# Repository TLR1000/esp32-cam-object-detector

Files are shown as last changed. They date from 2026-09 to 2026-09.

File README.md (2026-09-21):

# ESP32-CAM Object Detector / WildCam

Project voor een AI-Thinker ESP32-CAM met OV2640-camera. Eerste stap: camerabeeld live bekijken via het eigen wifi-netwerk van de ESP32-CAM. Bewegingsdetectie en de backend zijn beschreven in de ontwerpdocumenten en nog niet geïmplementeerd.

## Cameratest

De eerste sketch staat in [`camera-test`](camera-test/README.md), inclusief PlatformIO-configuratie, Arduino-sketch en aansluit-/flashinstructies.

Na flashen: voeding uit, GPIO0-GND-jumper verwijderen en opnieuw inschakelen. Met lokale wifi-instellingen in `camera-test/CameraTest/secrets.h` verbindt de camera met dat netwerk; open **http://wildcam-test.local/** of het IP-adres uit de seriële uitvoer. Deze instellingen blijven buiten Git.

Zonder wifi-instellingen of bij een mislukte verbinding is het test-accesspoint beschikbaar: **WildCam-Test**, wachtwoord **camera-test-32**, pagina **http://192.168.4.1/**. Dit wifi-netwerk biedt geen internet. De bediening van versie 2 werkt zonder JavaScript.

De browser toont MJPEG-livebeeld en kan een losse JPEG openen. Met PSRAM is de resolutie 800 × 600; zonder PSRAM 320 × 240. Gebruik voor de test één kijker tegelijk.

## Status van de verificatie

- PlatformIO-build voor `esp32cam` succesvol met Espressif32 6.12.0 / Arduino ESP32 2.0.17.
- Op 21 september 2026 succesvol geüpload via CP2102 op COM5 naar ESP32-D0WD revision 1.0; de uploader heeft de geschreven data geverifieerd.
- De gebruiker heeft werkend livebeeld via Skynet bevestigd. Detectieprestaties en vertraging zijn nog niet gemeten.

## Ontwerp en behuizing

**Begin voor nieuwe bouwtaken bij [BOUWINSTRUCTIE.md](BOUWINSTRUCTIE.md)**. Versie 1.1 bepaalt de camera-architectuur, prestatieproef, frame- en API-contracten, eventafsluiting en taakverdeling. De firmware- en backendteksten zijn daarop bijgewerkt. De Word-bestanden blijven ongewijzigde historische versies 1.0.

De genummerde documenten staan als Word-bestand en als leesbare tekst in de hoofdmap:

1. ESP32-CAM-firmwareontwerp.
2. Aansluiting en flashen via CP2102.
3. WildCam-backend op shoebox.

De bestaande STL-, 3DM- en G-code-bestanden bevatten het behuizingsontwerp en printmateriaal.

Gedownloade tools en gegenereerde buildbestanden worden via `.gitignore` buiten Git gehouden. Het wifi-wachtwoord hierboven is uitsluitend het vaste testwachtwoord; pas het aan voor een latere installatie.

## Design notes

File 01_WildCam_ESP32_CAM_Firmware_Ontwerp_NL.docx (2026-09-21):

# WildCam ESP32-CAM firmware

Softwareontwerp voor wildcam1, wildcam2, …

Implementatieontwerp • v1.0 • 21 september 2026

# 1. Doel en afbakening

Dit document specificeert de firmware voor klassieke AI-Thinker-achtige ESP32-CAM-borden met OV2640-camera en PSRAM. Iedere camera krijgt een vaste ID, bijvoorbeeld wildcam1 of wildcam2. De firmware detecteert lokaal dat een object de ingestelde Region of Interest (ROI) binnenkomt, maakt JPEG-opnamen en stuurt events naar de WildCam-backend op shoebox. Herkenning van ratten, muizen, katten of andere dieren op de server valt buiten v1, maar het protocol en datamodel worden daar nu al op voorbereid.

# 2. Ontwerpprincipes

- Detectie gebeurt lokaal en lichtgewicht; geen AI-inferentie op de ESP32.
- Veranderend buitenlicht mag niet voortdurend triggeren. Daarom gebruiken we frame-tot-frame verandering, ruimtelijke samenhang en onderdrukking van globale helderheidsveranderingen.
- Beeldopname mag nooit afhankelijk zijn van netwerklatentie. Uploaden draait onafhankelijk van camera en detectie.
- Zonder SD-kaart is PSRAM een begrensde best-effort wachtrij. Bij een volle buffer telt de firmware verloren frames, maar blokkeert de camera niet.
- Livebeeld is beschikbaar voor montage en uitrichten, maar is niet nodig tijdens normaal bedrijf.
- Verschillen tussen camera's zijn configuratie, geen aparte firmwarevarianten.

# 3. Platform en build

Onderdeel | Keuze
Bord | ESP32-CAM, AI-Thinker pinout, OV2640, naar verwachting 4 MB PSRAM
Framework | Arduino framework voor ESP32
Buildsysteem | Bij voorkeur PlatformIO; Arduino IDE blijft mogelijk
Netwerk | 2,4 GHz WiFi, DHCP; mDNS-hostnaam <camera_id>.local
Configuratie | NVS/Preferences; PSRAM voor tijdelijke JPEG-wachtrij
Transport | HTTP/1.1 op LAN, binaire JPEG-POSTs, korte time-outs en retry
Tijd | NTP indien beschikbaar; event-ID mag niet afhankelijk zijn van correcte kloktijd

# 4. Repository-indeling

wildcam-firmware/
platformio.ini
include/
config.h
camera_pins.h
types.h
src/
main.cpp
camera.cpp/.h
motion.cpp/.h
capture.cpp/.h
uploader.cpp/.h
webui.cpp/.h
settings.cpp/.h
status.cpp/.h
data/index.html
test/test_motion/
README.md

# 5. Runtime-architectuur

Cameraframes
|
+--> DETECTIEMODUS: lage resolutie
| -> ROI-blokstatistiek
| -> vergelijking met vorig frame
| -> trigger-state-machine
|
+--> EVENTMODUS: JPEG-opname
-> kopie naar PSRAM-wachtrij
-> cameraframebuffer direct vrijgeven

PSRAM-wachtrij ---> uploadtaak ---> shoebox /api/v1/frames
|
+-- retry/backoff bij fout

Lokale webserver voor setup/livebeeld draait onafhankelijk.

Gebruik FreeRTOS-taken en queues. De uploadtaak mag een blokkerende HTTP-call doen binnen zijn eigen taak, maar mag nooit de cameraframebuffer vasthouden of de detectietaak blokkeren.

# 6. Identiteit en configuratie

Sleutel | Voorbeeld | Betekenis
camera_id | wildcam1 | Unieke logische ID; patroon ^wildcam[1-9][0-9]*$
hostname | wildcam1 | Standaard gelijk aan camera_id
wifi_ssid / wifi_password | … | In NVS; wachtwoord nooit via status-API teruggeven
backend_url | http://shoebox:8088 | Basis-URL
roi | x,y,w,h | Genormaliseerde coördinaten 0..1000
detect_fps | 5 | Standaard 5 detectieframes/s
trigger_frames | 2 van 3 | Debounce
event_seconds | 3.0 | Opnameduur na trigger
event_fps | 3 | JPEG's per seconde tijdens event
jpeg_framesize | SVGA | Start met 800x600
jpeg_quality | 12 | ESP32-camera kwaliteitswaarde
motion_threshold | instelbaar | Drempel voor blokverandering
global_change_limit | instelbaar | Onderdruk globale lichtverandering
cooldown_ms | 2000 | Voorkomt event-storm

# 7. Bewegings-/objectdetectie

1. Neem ongeveer 5 keer per seconde een klein detectieframe en bereken luminantie (Y) van bemonsterde pixels.
2. Beperk de analyse tot de ingestelde ROI.
3. Verdeel de ROI in blokken en bereken per blok de gemiddelde luminantie.
4. Vergelijk ieder blok met hetzelfde blok in het vorige frame. Markeer een blok als veranderd wanneer |Yt - Yt-1| boven de drempel komt.
5. Bepaal de globale helderheidsverandering met mediaan of trimmed mean van de blokverschillen en compenseer deze common-mode verandering.
6. Verwerp een frame als waarschijnlijke lichtverandering wanneer een te groot deel van de ROI tegelijk en in dezelfde richting verandert.
7. Eis een ruimtelijk aaneengesloten cluster én een trigger in 2 van 3 opeenvolgende vergelijkingen.
8. Ga daarna naar EVENTMODUS, maak gedurende event_seconds JPEG's met event_fps en keer na cooldown terug naar detectie.

Gebruik in v1 geen vast achtergrondreferentiebeeld. Buiten is frame-tot-frame vergelijking robuuster tegen bewolking, zon en schemering. Een adaptief achtergrondmodel kan later worden toegevoegd.

# 8. Event- en buffermodel

Een event wordt uniek geïdentificeerd door (camera_id, boot_id, event_id). boot_id is een willekeurige 32-bit waarde per boot; event_id is een oplopende persistente teller.

Veld | Type | Voorbeeld
camera_id | string | wildcam1
boot_id | uint32 hex | 7fa31c09
event_id | uint64 | 1842
frame_index | uint16 | 0..N-1
capture_ms | uint64 | milliseconden sinds boot
captured_at | ISO-8601 optioneel | alleen bij gesynchroniseerde klok
rssi | int | -72

Een queue-entry bezit een eigen kopie van de JPEG in PSRAM. Begrens op totaal aantal bytes. Startwaarde: maximaal circa 2,0 MiB JPEG-data, zodat camera en WiFi voldoende geheugen overhouden. Als een nieuwe JPEG niet past: frame laten vallen, dropped_frames verhogen en doorgaan.

# 9. Protocol naar backend

POST {backend_url}/api/v1/frames

Content-Type: image/jpeg
X-WildCam-ID: wildcam1
X-Boot-ID: 7fa31c09
X-Event-ID: 1842
X-Frame-Index: 2
X-Capture-Millis: 12345678
X-Captured-At: 2026-09-21T14:53:21.412+02:00
X-RSSI: -72
X-Firmware-Version: 1.0.0
X-Protocol-Version: 1

Verwijder een frame pas uit de PSRAM-wachtrij na een 2xx-response. Retry netwerkfouten en 5xx met exponentiële backoff, bijvoorbeeld 1, 2, 5, 10, 30 en maximaal 60 seconden. 4xx is een configuratie-/protocolfout en mag geen snelle retry-loop veroorzaken.

# 10. Lokale webinterface

Endpoint | Functie
GET / | Status/setup, preview, ROI-overlay en detectorwaarden
GET /snapshot.jpg | Een JPEG
GET /stream | MJPEG-livebeeld voor uitrichten
GET /api/status | ID, IP, RSSI, uptime, queue, drops, laatste trigger/backendstatus
GET /api/config | Configuratie zonder WiFi-wachtwoord
POST /api/config | Valideren en persistent opslaan
POST /api/reboot | Herstart
POST /api/test-upload | Maak en upload één testbeeld

Teken de ROI als overlay op het livebeeld. Gebruik genormaliseerde ROI-coördinaten zodat dezelfde rechthoek klopt bij detectie- en JPEG-resolutie. Tijdens streaming mag de detectiefrequentie tijdelijk lager worden.

# 11. Toestanden en foutafhandeling

BOOT -> CAMERA_INIT -> WIFI_CONNECTING -> RUN
RUN:
DETECTING --trigger--> CAPTURING_EVENT --klaar--> COOLDOWN --> DETECTING
uploadtaak draait parallel
WiFi-uitval stopt detectie/opname niet

- Bij camerafout: duidelijke seriële diagnose en gecontroleerde retry/herstart.
- Bij WiFi-uitval: detectie en opname gaan door totdat de begrensde PSRAM-buffer vol is.
- Seriële logging op 115200 baud: bootreden, PSRAM, camera, WiFi/IP, mDNS en backendfouten.
- Tel detections, events, frames_captured, frames_uploaded, dropped_frames, upload_failures en camera_failures.
- Stuur bij voorkeur iedere 60 s een heartbeat naar /api/v1/heartbeat. Een mislukte heartbeat is niet fataal.

# 12. Voorbereiding op latere AI

De firmware kent geen diersoorten. Originele JPEG's en stabiele event-/framemetadata blijven behouden. De backend kan later velden toevoegen als species, confidence, model_name en model_version zonder wijziging van het cameraprotocol.

# 13. Acceptatiecriteria voor Codex

- wildcam1 en wildcam2 draaien dezelfde binary met verschillende NVS-configuratie.
- Detectie blijft lopen terwijl een HTTP-upload blokkeert of time-out.
- Backend-uitval kan geen onbeperkt RAM gebruiken; verloren frames worden geteld.
- Globale lichtverandering in de ROI triggert normaal niet; lokale beweging wel.
- <camera_id>.local toont preview/livebeeld en zichtbare ROI.
- Testevent bereikt shoebox met correcte camera-, event- en framemetadata.
- Na reboot ontstaan geen event-ID-collisies.
- WiFi-herstel gebeurt automatisch.
- Code is modulair en README bevat build-, flash- en configuratiestappen.

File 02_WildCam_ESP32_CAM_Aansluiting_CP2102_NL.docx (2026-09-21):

# WildCam ESP32-CAM aansluiting en flashen

Aansluitschema inclusief CP2102 USB-naar-TTL/UART-adapter

Implementatieontwerp • v1.0 • 21 september 2026

# 1. Doel

Dit document beschrijft de aansluiting van de klassieke AI-Thinker-achtige ESP32-CAM voor WildCam op een CP2102 USB-naar-TTL/UART-adapter, inclusief programmeren, voeding en normaal bedrijf. Voor v1 is geen SD-kaart nodig.

# 2. Elektrische uitgangspunten

- Voed de ESP32-CAM via de 5V-pin; de onboard regelaar maakt 3,3 V.
- UART-logica moet 3,3 V TTL-compatibel zijn.
- Voed de ESP32-CAM niet uit de 3,3V-uitgang van de CP2102; camera en WiFi veroorzaken stroompieken.
- Als de 5V/VBUS-pin van de CP2102 rechtstreeks USB-5V levert en voldoende stroom kan leveren, mag die op de werkbank de 5V-pin voeden. Bij twijfel: aparte gestabiliseerde 5V-voeding van minimaal circa 1 A en gemeenschappelijke GND.
- Verbind een externe 5V-voeding niet tegelijk met de 5V-uitgang van de adapter tenzij de voedingsopzet daar expliciet voor is ontworpen.

# 3. Aansluitingen voor programmeren

CP2102 | ESP32-CAM | Functie
5V / VBUS | 5V | Werkbankvoeding indien adapter/kabel voldoende levert
GND | GND | Gemeenschappelijke massa
TXD | U0R / GPIO3 | Adapter TX -> ESP32 RX
RXD | U0T / GPIO1 | Adapter RX <- ESP32 TX
— | GPIO0 -> GND | Tijdelijke jumper om seriële bootloader te kiezen

# 4. Schema

PC USB
|
v
+------------------+ +----------------------+
| CP2102 USB-UART | | ESP32-CAM |
| | | |
| 5V/VBUS ----------+----------------------> 5V |
| GND -------------+----------------------> GND |
| TXD -------------+----------------------> U0R / GPIO3 |
| RXD <------------+----------------------- U0T / GPIO1 |
+------------------+ | |
| GPIO0 ---- jumper ---+
| naar GND |
+----------------------+

ALLEEN FLASHEN: GPIO0 aan GND tijdens reset/inschakelen.
NORMAAL BOOTEN: GPIO0 los van GND en daarna reset/power-cycle.

# 5. Variant met aparte voeding

+5 V gestabiliseerd (>=1 A) ------> ESP32-CAM 5V
Voeding GND ------------------------+-----> ESP32-CAM GND
|
CP2102 GND -------------------------+
CP2102 TXD -------------------------------> U0R
CP2102 RXD <------------------------------- U0T

CP2102 5V/VBUS in deze variant NIET aansluiten.

# 6. Flashprocedure

1. Schakel voeding/USB uit. Verbind TXD->U0R, RXD->U0T en GND->GND.
2. Verbind GPIO0 met GND.
3. Sluit 5V/USB aan.
4. Selecteer AI Thinker ESP32-CAM in PlatformIO/Arduino en begin conservatief met 115200 baud uploadsnelheid.
5. Als de uploader wacht op verbinding: druk eenmaal op reset terwijl GPIO0 nog aan GND ligt.
6. Na succesvolle upload: voeding uit.
7. Verwijder de GPIO0-GND-jumper.
8. Voeding weer aan. De WildCam-firmware start nu normaal.
9. Open de seriële monitor op 115200 baud voor camera-ID, IP en diagnose.

# 7. Normale aansluiting in het veld

5 V voeding ----> ESP32-CAM 5V
GND ----> ESP32-CAM GND

GPIO0: los laten voor normaal booten.
U0R/U0T: optioneel beschikbaar als service/debug-header.
CP2102: niet nodig tijdens normaal bedrijf.

# 8. Pinconflicten

De ESP32-CAM heeft weinig vrije GPIO's. De camera gebruikt al veel pinnen. De microSD-interface deelt op veel AI-Thinker-borden GPIO2, 4, 12, 13, 14 en 15. V1 gebruikt geen SD; wijs deze pinnen later niet zomaar toe zonder de exacte boarddefinitie te controleren. De witte onboard flits-LED zit doorgaans op GPIO4 en deelt daarmee een SD-functie.

# 9. Voedingsbetrouwbaarheid

- Gebruik tijdens flashen een korte, goede USB-kabel.
- Gebruik in het veld een gestabiliseerde 5V-voeding met marge; 1 A of meer is praktisch.
- Brownout-resets tijdens WiFi-transmissie wijzen meestal op spanningsval in voeding/kabel.
- Bij langere laagspanningskabels voldoende aderdoorsnede gebruiken.
- ESP32-CAM en CP2102 zijn niet weerbestendig; monteer droog en met trekontlasting.

# 10. Problemen oplossen

Probleem | Waarschijnlijke oorzaak / actie
Failed to connect / packet header | GPIO0 niet laag bij reset; TX/RX kruisen; reset indrukken
Onleesbare seriële tekst | Verkeerde baudrate; WildCam gebruikt 115200
Herhaalde brownout/reset | 5V-voeding of kabel te zwak
Camera init faalt | Boardselectie/pinmap/ribbonconnector controleren
Blijft in downloader | GPIO0 zit nog aan GND
Geen seriële output | GND, U0T->RXD, voeding en juiste COM-poort controleren

# 11. Deliverables voor Codex

- README met deze aansluittabel en flashprocedure.
- platformio.ini met correcte ESP32-CAM target en 115200 seriële monitor.
- camera_pins.h met expliciete AI-Thinker camera-pinmapping.
- Na deployment geen afhankelijkheid van de CP2102.

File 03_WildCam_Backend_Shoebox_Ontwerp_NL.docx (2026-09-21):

# WildCam backend op shoebox

Ontwerp voor ingestie, opslag, webinterface en beheer

Implementatieontwerp • v1.0 • 21 september 2026

# 1. Doel

De WildCam-backend ontvangt JPEG-frames van meerdere ESP32-CAM's (wildcam1, wildcam2, …), slaat ze betrouwbaar op, registreert metadata en biedt een eenvoudige browserinterface voor bekijken en beheer. V1 doet nog geen server-side herkenning van ratten, muizen, katten of andere dieren. De architectuur reserveert daarvoor wel een nette asynchrone uitbreidingsroute.

# 2. Deployment-uitgangspunten

Onderdeel | Keuze
Host | Linux-server shoebox
Runtime | Python 3.12+
Framework | FastAPI + Uvicorn
Metadata | SQLite in WAL-modus
Beelden | Filesystem onder /opt/wildcam/data
Root | /opt/wildcam
Luisterpoort | 0.0.0.0:8088 op vertrouwd LAN
Frontend | Server-rendered HTML/Jinja2 + kleine hoeveelheid vanilla JavaScript
Reverse proxy | Later optioneel; niet vereist voor LAN-v1

# 3. Repository-indeling

wildcam-backend/
pyproject.toml
README.md
wildcam/
main.py
config.py
db.py
models.py
ingest.py
storage.py
api.py
ui.py
schemas.py
housekeeping.py
templates/
base.html
dashboard.html
camera.html
event.html
admin.html
static/app.css
static/app.js
tests/
test_ingest.py
test_idempotency.py
test_storage.py
test_ui.py
deploy/
wildcam.service
wildcam.env.example

# 4. Opslagstructuur

/opt/wildcam/
app/
data/
captures/
wildcam1/
2026/09/21/
7fa31c09_0000001842/
000.jpg
001.jpg
002.jpg
wildcam2/...
wildcam.sqlite3
logs/ # optioneel; journald mag ook

Schrijf een upload eerst naar een tijdelijk bestand op hetzelfde filesystem, sluit/synchroniseer waar passend en rename daarna atomair naar de definitieve .jpg. Een 2xx-response betekent dat de backend het frame lokaal duurzaam heeft geaccepteerd.

# 5. Datamodel

Tabel | Belangrijkste velden
cameras | camera_id PK, first_seen, last_seen, last_ip, last_rssi, firmware_version, last_boot_id, status_json
events | id PK, camera_id, boot_id, event_id, first_capture_at, last_capture_at, received_at, frame_count, classification_status, notes
frames | id PK, event_fk, frame_index, capture_ms, captured_at nullable, received_at, relative_path, bytes, sha256, rssi, width/height nullable
classifications (later) | id PK, frame/event FK, species, confidence, model_name, model_version, created_at, raw_json
settings | key PK, value_json

Maak een unieke constraint op (camera_id, boot_id, event_id, frame_index). Daardoor zijn retries idempotent en ontstaan geen dubbele frames.

# 6. Ingestie-API

## 6.1 POST /api/v1/frames

Accepteer Content-Type image/jpeg plus de WildCam-headers uit het firmwaredocument. Valideer camera_id, numerieke velden, content-type en maximale bodygrootte (start met 1 MiB per JPEG). Stream naar disk en voorkom onbeperkte request-buffers.

201 Created
{"ok": true, "stored": true, "frame_id": 12345}

200 OK # exacte retry
{"ok": true, "stored": false, "duplicate": true, "frame_id": 12345}

400/413/422
{"ok": false, "error": "..."}

## 6.2 POST /api/v1/heartbeat

Ontvang ongeveer iedere 60 seconden camerastatus en werk cameras.last_seen en operationele velden bij.

{
"camera_id": "wildcam1",
"boot_id": "7fa31c09",
"uptime_s": 12345,
"ip": "192.168.1.80",
"rssi": -72,
"queue_frames": 3,
"queue_bytes": 238112,
"dropped_frames": 0,
"upload_failures": 2,
"firmware_version": "1.0.0"
}

## 6.3 Lees- en beheer-API

Endpoint | Functie
GET /api/v1/cameras | Camera's en online/offline-status
GET /api/v1/cameras/{id} | Details en tellers
GET /api/v1/events?camera_id=&from=&to=&limit= | Gepagineerde eventlijst
GET /api/v1/events/{id} | Event + framemetadata
GET /api/v1/frames/{id}/image | JPEG serveren
PATCH /api/v1/events/{id} | Notitie / later handmatige tags
DELETE /api/v1/events/{id} | Verwijderen met expliciete UI-bevestiging
GET /api/v1/health | Proces-, database- en opslagstatus

# 7. Webinterface

## 7.1 Dashboard /

- Camerakaarten met camera_id, online/offline, laatst gezien, RSSI, firmware en queue/drop-tellers.
- Recente events over alle camera's, nieuwste eerst, met thumbnail, camera-ID, tijd en aantal frames.
- Filters op camera en datum.
- Opslagoverzicht met aantallen events/frames en schijfgebruik.

## 7.2 Camerapagina /cameras/{camera_id}

- Camerametadata en laatste heartbeat.
- Gemakslink naar bijvoorbeeld http://wildcam1.local/; backend mag hiervan niet afhankelijk zijn.
- Chronologische eventgalerij.
- Waarschuwingen bij oude heartbeat, veel uploadfouten of dropped frames.

## 7.3 Eventpagina /events/{id}

- Alle frames in volgorde met tijden en metadata.
- Grote viewer met vorige/volgende.
- Originele JPEG openen/downloaden.
- Beheernotitie en verwijderactie.
- Gereserveerd classificatiepaneel dat in v1 'Niet geclassificeerd' toont.

# 8. Online/offline

Leid status af uit last_seen; sla online niet als waarheid op. Bij heartbeat iedere 60 s kan bijvoorbeeld na 180 s 'offline/stale' worden getoond. Toon altijd ook de werkelijke laatst-gezien-tijd.

# 9. Beveiliging

- V1 is voor een vertrouwd LAN; poort 8088 niet rechtstreeks op internet publiceren.
- Valideer camera-ID en headers; gebruik nooit ruwe headertekst direct als filesystempad.
- Bij voorkeur per camera een ingest-token via Authorization: Bearer <token>.
- Destructieve beheeracties vereisen minimaal een eenvoudige admin-authenticatie als andere LAN-gebruikers toegang hebben.
- Serve bestanden alleen via database-ID/pathlookup en blokkeer directory traversal.

# 10. Betrouwbaarheid en concurrency

- SQLite WAL; transacties kort houden.
- Bestand eerst atomair opslaan, daarna metadata transactioneel registreren; wees expliciet over cleanup/quarantaine bij DB-fout.
- Unieke constraint maakt retries veilig.
- Geen 2xx teruggeven voordat het beeld lokaal veilig is geaccepteerd.
- Request/body/time-limieten; één defecte camera mag andere camera's niet blokkeren.
- Gestructureerde logs met camera_id, boot_id, event_id en frame_index.

# 11. Haak voor toekomstige AI

Na succesvolle ingestie kan intern een 'frame/event opgeslagen'-job worden aangeboden. In v1 is dit een no-op. Later kan een worker YOLO of een andere classifier draaien. AI-resultaten staan los van de onveranderlijke capturemetadata.

class ClassificationService:
async def enqueue_event(self, event_db_id: int) -> None:
# v1: niets doen
# later: event naar AI-workerqueue sturen
...

Classificeer later bij voorkeur op eventniveau nadat alle frames binnen zijn of na een korte inactiviteitstime-out. Zo kan de server het scherpste frame kiezen en dubbele inferentie vermijden.

# 12. Configuratie

WILDCAM_BIND=0.0.0.0
WILDCAM_PORT=8088
WILDCAM_DATA_DIR=/opt/wildcam/data
WILDCAM_DB=/opt/wildcam/data/wildcam.sqlite3
WILDCAM_MAX_JPEG_BYTES=1048576
WILDCAM_OFFLINE_AFTER_SECONDS=180
WILDCAM_ADMIN_SECRET=change-me
WILDCAM_LOG_LEVEL=INFO

# 13. systemd

Voor deze zelfstandige, altijd beschikbare ingestieservice is systemd passend.

[Unit]
Description=WildCam backend
After=network-online.target
Wants=network-online.target

[Service]
Type=simple
User=wildcam
Group=wildcam
WorkingDirectory=/opt/wildcam/app
EnvironmentFile=/etc/wildcam.env
ExecStart=/opt/wildcam/venv/bin/uvicorn wildcam.main:app --host 0.0.0.0 --port 8088
Restart=on-failure
RestartSec=3

[Install]
WantedBy=multi-user.target

# 14. Tests voor Codex

- Geldige JPEG van wildcam1 opslaan en file + DB-record verifiëren.
- Exact hetzelfde frame opnieuw sturen: 200/idempotent, geen duplicaat.
- Zelfde event/frame-nummers van wildcam2 blijven apart.
- Ongeldige camera-ID, niet-JPEG en te grote body weigeren.
- Gelijktijdige uploads van meerdere camera's testen.
- Eventvolgorde en filters op camera/datum testen.
- Oude heartbeat leidt tot afgeleide offline-status.
- Delete verwijdert databasegegevens en bestanden consistent.
- Padconstructie kan nooit buiten capture-root komen.
- AI-tabellen/interfaces bestaan als uitbreidingspunt, maar v1 vereist geen model of AI-package.

# 15. Definition of Done

- wildcam1 en wildcam2 kunnen tegelijk uploaden.
- Beelden zijn per camera en event in de browser te bekijken.
- Backendrestart verliest geen beelden of metadata.
- Retries maken geen duplicaten.
- Dashboard toont camerahealth en recente captures.
- README bevat installatie, venv, configuratie, systemd, backup en upgrade.
- Databaseschema is migratieklaar; Alembic aanbevolen voor latere AI-uitbreidingen.

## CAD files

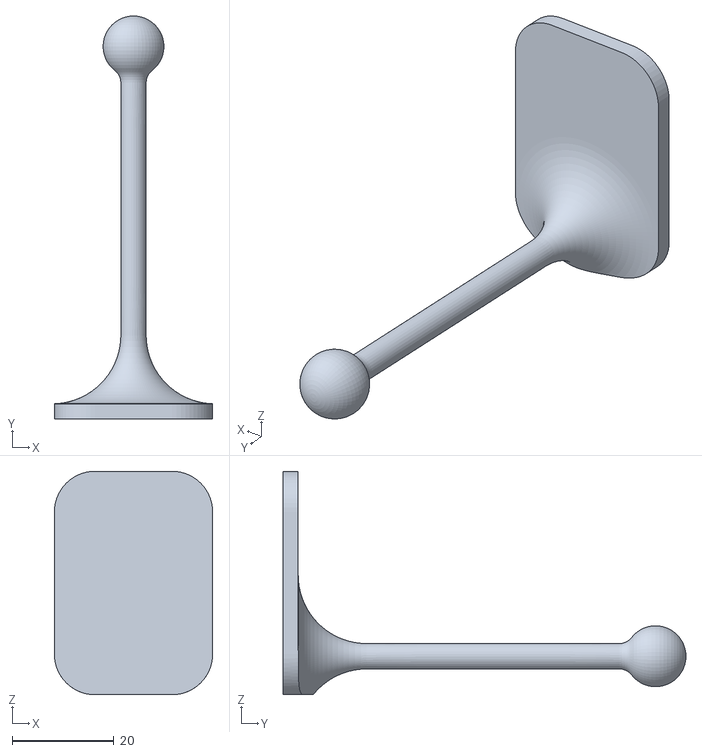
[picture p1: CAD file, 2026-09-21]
stand.stl
31.2 x 79.4 x 44.0

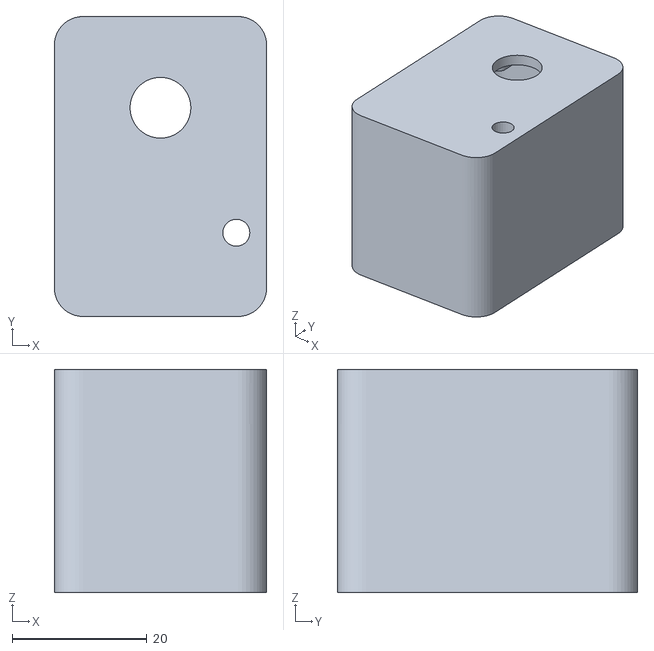
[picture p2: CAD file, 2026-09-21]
esp32_cam_housing.stl
31.5 x 44.5 x 33.2

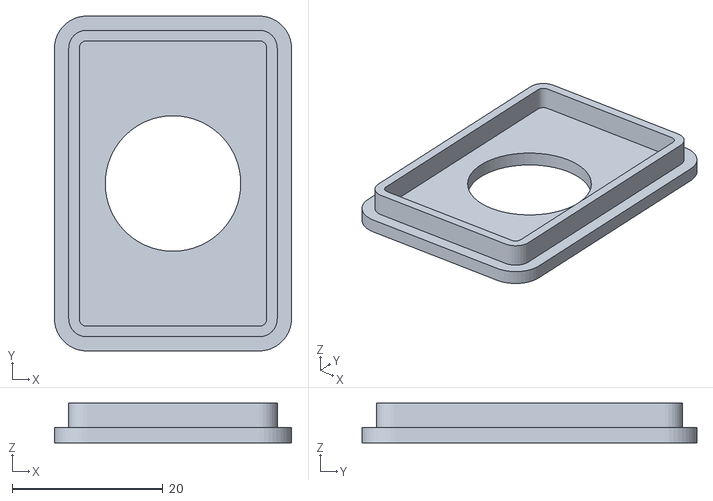
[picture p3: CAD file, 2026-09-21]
back-plate.stl
31.5 x 44.5 x 5.25

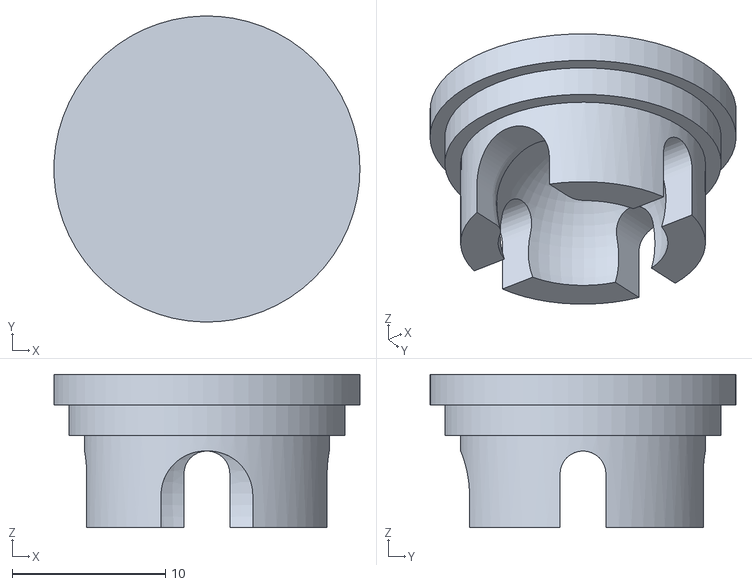
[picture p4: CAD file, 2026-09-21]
back-holder.stl
20.0 x 20.0 x 10.0

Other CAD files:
esp32cam_new.3dm

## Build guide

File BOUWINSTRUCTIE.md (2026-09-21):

# WildCam bouwinstructie

Versie 1.1 — 21 september 2026

Deze specificatie bepaalt de interfaces, taakverdeling en acceptatie voor de parallelle bouw van WildCam. Lees daarnaast document 01 voor firmware, 02 voor bedrading en 03 voor de backend. Dit document is leidend voor gedeelde contracten. De ongewijzigde Word-documenten zijn historische versies 1.0 en geen actuele bouwinstructies.

## Bewezen uitgangspunt en scope

De AI-Thinker ESP32-CAM met OV2640 kan JPEG-beelden leveren en livebeeld via bestaande wifi tonen. De gebruiker heeft dit bevestigd met `camera-test`. De haalbare detectiesnelheid, beschikbare PSRAM, vertraging en betrouwbaarheid bij weinig licht zijn nog niet gemeten. De testsketch is een apart diagnoseprogramma en geen basis om netwerkcode in de detectorlus over te nemen.

V1 detecteert lokale beweging binnen een ROI en bewaart events met JPEG-beelden. Dierherkenning gebeurt later op de server. Hardware gebruikt 2,4GHz-wifi, een CP2102 voor flashen en voorlopig geen SD-kaart. Netwerkgegevens en tokens blijven buiten Git. De bestaande behuizingsbestanden blijven behouden.

## Volgorde en eigenaarschap

1. Leg de onderstaande contracten vast in `contracts/`: C++-headers, JSON Schema/OpenAPI en gedeelde geldige en ongeldige testfixtures. Er is één integratieverantwoordelijke voor contractwijzigingen. Wijzigingen aan een contract vereisen gelijktijdige aanpassing van producent, consument en fixtures.
2. Camera/prestatiemetingen, detector, backend en webinterface mogen daarna onafhankelijk worden gebouwd. Alleen de camera-implementatie en definitieve configuratie wachten op de hardwaremeting; de andere taken gebruiken fixtures en mocks.
3. Integreer eerst één camera naar één backend, daarna meerdere camera's, verstoringen en de fysieke detectieproef. Alleen de camera/integratietaak flasht het gedeelde apparaat. Andere taken flashen niet zelfstandig.

| Taak | Bestanden en verantwoordelijkheid | Afhankelijkheid en resultaat |
| --- | --- | --- |
| Camera en firmwareintegratie | `wildcam-firmware/`, behalve de detectormodule; centrale camera-eigenaar, geheugen, netwerk, uploader, eventbesturing en metingen | Implementeert framecontract en protocol; levert meetrapport en flashbare firmware |
| Bewegingsdetectie | `wildcam-firmware/src/motion.*`, bijbehorende hosttests en fixtures | Verwerkt uitsluitend GrayFrameView; levert scores en bewegingsbesluit zonder hardware- of netwerktoegang |
| Backend | `wildcam-backend/`, behalve templates/static | Implementeert contracten voor ingestie, events, opslag, status en beheer |
| Webinterface | Backendtemplates/static en UI-tests | Gebruikt vastgelegde backendresponses; implementeert geen eigen opslag- of ingestielogica |

De firmwareintegratietaak beheert ook de lokale camerawebpagina. Zo wijzigen backend-UI en firmwaretaken niet dezelfde bestanden. Gebruik per taak een eigen branch/worktree; gedeelde contracten worden eerst gepubliceerd. De gebruiker start de taken afzonderlijk.

## Framecontract

Alle camera-drivercalls en wijzigingen aan sensor/resolutie lopen via één camera-eigenaar. Consumers krijgen nooit een `camera_fb_t*`. Opname, analyse en netwerk hebben begrensde wachtrijen en een expliciet maximumaantal buffers. Alleen analyse heeft voorrang; livebeeld is optioneel en mag frames overslaan.

`GrayFrameView` bevat `sequence` (uint64), `capture_us` (uint64, monotone microseconden sinds boot bij begin van opname), `width`, `height`, `stride` en `pixels` (8-bit luminantie). De pixels zijn alleen geldig gedurende `MotionDetector.process(frame, config)`. De detector bewaart geen pointer en doet geen allocaties per frame, I/O, sleeps of camera-drivercalls. De camera-eigenaar of adapter maakt de luminantiegegevens; JPEG-decodering hoort niet bij de detector.

`MotionResult` bevat dezelfde sequence/capture_us, een bewegingsscore, globale lichtverandering, het aantal aaneengesloten veranderde blokken en `candidate`. De eventcontroller beslist met een tijdvenster over bevestiging en eventgrenzen. ROI is x/y/w/h in 0..1000, na toepassing van vaste beeldoriëntatie; valideer w/h > 0 en x+w/y+h <= 1000. Normaliseer alle resoluties naar hetzelfde zichtveld. Wisseling van oriëntatie, ROI of resolutie reset het vergelijkingsmodel en wordt als meetonderbreking geregistreerd.

Een JPEG voor netwerk of eventopslag is een eigen kopie in een begrensde bufferpool. De camerabuffer wordt teruggegeven voordat netwerkverzending begint. Bezit gaat bij enqueue naar de consumer; die geeft de kopie vrij na aflevering of definitieve verwijdering. Dubbele vrijgave, vasthouden van een driverbuffer door een consumer en onbeperkte allocaties zijn verboden.

Livebeeld heeft maximaal één wachtend recent frame per kijker en maximaal één kijker in v1. Een nieuw frame vervangt een nog niet verzonden frame; een reeds verzonden frame wordt niet gemuteerd. Een langzaam netwerk mag geen FIFO met steeds ouder livebeeld opbouwen. Begrens ook de actieve verzendbuffer. Preview en uploader krijgen geen voorrang op detectie.

## Hardwareproef en geheugenbudget

Vergelijk minimaal 320x240, 640x480 en 800x600 JPEG. Meet per profiel zonder kijker, met één kijker en met vertraagde/offline backend. Leg ook lichtniveau, cameraoriëntatie, voeding, RSSI, firmwareversie en PSRAM vast. Onderzoek twee routes: JPEG opnemen en verkleinen naar luminantie, of expliciete sensor/resolutiewissels. Kies pas daarna de productieroute; meet bij wisselen de duur, onbruikbare overgangsframes en detectieonderbreking.

Rapporteer werkelijk ontvangen detectieframes/s, maximale tijd tussen geanalyseerde opnamen, frameleeftijd bij analyse en verzenden, analyse- en verzendtijden (p50/p95/max), JPEG-grootte, vrije/minimale PSRAM en grootste vrije blok. Bepaal frametijden uit opname-timestamps, niet alleen uit hoe snel `fb_get` terugkomt. Browserweergavevertraging vereist een afzonderlijke visuele proef met een zichtbare klok of beweging.

Budgetteer driverbuffers, decode-/analysewerkruimte, pretriggerbuffer, uploadwachtrij, actieve netwerkbuffers en veiligheidsmarge samen. De eerdere vaste uploadreservering van 2 MiB vervalt. De som moet onder het werkelijk gemeten beschikbare geheugen blijven, ook bij piekframes. Geen heapallocatie bij ieder detectieframe. Bij ontbrekende PSRAM: expliciete degraded-status en apart gevalideerd profiel; geen stilzwijgende volledige prestatieclaim.

## Detectie en events

De voorlopige acceptatiedoelstelling is ten minste 95 detecties uit 100 passages waarbij een afgesproken testobject minimaal 300 ms in de ROI zichtbaar is. Dit is een te toetsen doel, geen bewezen eigenschap. Leg vóór de proef objectgrootte, afstand, snelheid, ROI, lichtcondities en grondwaarheid vast. Meet detectiekans en tijd van eerste zichtbaarheid tot trigger. Rapporteer snelle/korte passages apart. Een niet gehaald doel is een blokkade voor de prestatieclaim, geen reden om de grens stilzwijgend te verlagen.

Start onderzoek rond 10 detectieframes/s en een maximale analyse-onderbreking van 100 ms; dit zijn startdoelen, geen hardwaregaranties. Kies definitieve frequentie en tijdbevestiging op basis van de proef. De oude harde instelling 5 fps en 2 van 3 frames is vervangen door configureerbare tijdbevestiging die ook onregelmatige intervallen controleert. Een groot framegat mag niet als aaneengesloten bewijs tellen. Rapporteer daarnaast valse events in een vaste lege scène en bij globale lichtwisselingen; leg de acceptatiegrens vast vóór de eindproef.

Bewaar beoogd 0,5–1 seconde JPEG-voorgeschiedenis in een ringbuffer, begrensd op bytes en frames. Bij bevestiging blijven de beschikbare pretriggerframes behouden voor het event. Leg werkelijke pretriggerdekking vast; een kleinere dekking bij geheugendruk wordt zichtbaar gemeld. Pretriggerbeelden mogen een lagere resolutie hebben dan bewijsfoto's. Bufferbeheer mag de detectie niet laten wachten.

Beweging verlengt een event. Startwaarden: posttrigger 3 s, bewijsfoto's 3 fps en maximale eventduur 30 s. Bij aanhoudende beweging volgt na 30 s een nieuw event met `previous_event_id`; detectie blijft doorgaan. Er is geen blinde cooldown. Frame-indexen zijn vanaf 0 per event in opnamevolgorde; elke voor een event geselecteerde opname krijgt een index, ook als deze later verloren gaat. Een niet gemaakte geplande opname telt als `capture_failure`, niet als verzonnen frame. Sorteer pretriggerframes vóór triggerframes. Tijdgrenzen zijn configureerbaar en worden in fixtures getest.

## Gemeenschappelijk netwerkcontract versie 1

De nog te bouwen productie-API gebruikt `/api/v1`. `protocol_version` is 1; firmwareversie staat daar los van. Timestamps zijn UTC RFC3339 wanneer gesynchroniseerd, anders null/afwezig. `capture_ms` en `capture_us` zijn monotone tijden sinds boot, geen epoch. Ontvangsttijd wordt altijd door de backend vastgelegd. `clock_synced` hoort per frame bij het moment van opname.

Frame-identiteit: `(camera_id, boot_id, event_id, frame_index)`. Camera-ID voldoet aan `^wildcam[1-9][0-9]*$`. `boot_id` is 32 hextekens met 128 willekeurige bits per boot; event_id is een oplopende teller binnen die boot. Deze afspraak vervangt de oude 8-hex boot-ID en persistente eventteller. JSON encodeert event_id, previous_event_id en uint64-tijden als decimale strings om precisieverlies in JavaScript te voorkomen. Frame-indexen en aantallen blijven begrensde JSON-integers. Voorbeelden gebruiken `7fa31c09000000000000000000000001` als boot-ID.

`POST /api/v1/frames` ontvangt image/jpeg met headers X-WildCam-ID, X-Boot-ID, X-Event-ID, X-Frame-Index, X-Capture-Millis, X-Clock-Synced (true/false), X-RSSI, X-Firmware-Version en X-Protocol-Version (1). X-Captured-At is verplicht bij clock_synced=true en ontbreekt anders. X-Frame-Phase is pretrigger of event. De backend valideert/decodeert JPEG binnen byte- en pixelgrenzen. SHA256 wordt door de backend berekend. Identieke retry betekent dezelfde JPEG en dezelfde onveranderlijke opnamemetadata; RSSI en firmwareversie zijn die bij opname en blijven gelijk tijdens retries.

201 = duurzaam nieuw frame; 200 = exacte retry; 409 = dezelfde identiteit met andere inhoud of opnamemetadata. De bestaande responses met ok/stored/frame_id blijven behouden; frame_id is een decimale string. 400/413/415/422 zijn permanente requestfouten. 401/403 pauzeren upload voor die camera en melden een configuratiefout. Netwerkfouten, 408, 429 en 5xx krijgen begrensde backoff met jitter; respecteer Retry-After binnen de ingestelde bovengrens. Andere 4xx blokkeren de wachtrij niet: tel en registreer het afgewezen item en ga verder. Geen verwijdering bij een onbegrepen of ongeldige succesresponse.

`POST /api/v1/events/close` ontvangt een idempotente definitieve afsluiting: camera_id, boot_id, event_id, previous_event_id (string of null), first_capture_ms, last_capture_ms, trigger_ms, selected_frames, uploaded_frames, dropped_frames, capture_failures, pretrigger_frames, pretrigger_coverage_ms en reason (quiet/max_duration/manual). Tijden zijn decimale strings; coverage is een begrensd integer in ms. Afsluiten gebeurt nadat alle lokale frame-items voor dit event zijn bevestigd of definitief afgevoerd; dan geldt selected_frames = uploaded_frames + dropped_frames. Reserveer een aparte begrensde wachtrij voor afsluitberichten. Ook een event met nul geaccepteerde frames mag worden afgesloten.

Een afsluiting mag de backend bereiken voordat alle frametransacties zichtbaar zijn; de backend accepteert beide volgorden. Exact herhalen geeft 200, eerste afsluiting 201, afwijkende afsluiting 409. Ontvangen frames zijn de backendwaarheid. `capture_closed` betekent dat de camera klaar is; `delivery_complete` betekent dat het aantal duurzaam ontvangen frames gelijk is aan uploaded_frames. `has_loss` volgt uit dropped_frames/capture_failures. Inconsistenties worden zichtbaar en overschrijven geen eerdere gegevens. Een inactiviteitstime-out markeert uitsluitend stale/incomplete, nooit bewezen compleet. Na stroomverlies blijven niet-afgesloten events incomplete; PSRAM biedt geen duurzaamheid.

Heartbeat elke 60 s; backend stale na 180 s. JSON bevat naast bestaande tellers protocol_version, clock_synced, camera_ready, psram_available, capture_fps, detect_fps, max_detect_gap_ms, analysis_p95_ms, frame_age_p95_ms, send_p95_ms, jpeg_bytes_mean, psram_free_bytes, psram_min_free_bytes, queue_frames/bytes en dropped_by_reason. Dropreasons zijn pretrigger_evicted, preview_replaced, upload_queue_full, permanent_reject en age_expired. Normale ringbufferrotatie en previewvervanging tellen niet als verloren eventframes. Tellers resetten per boot. Percentielen gebruiken het laatste volledige venster van 60 s; zonder samples is de waarde null.

## Gezamenlijke acceptatie

- De detector werkt op vaste opnamereeksen zonder camera of netwerk en reproduceert resultaten met dezelfde configuratie.
- De fysieke passageproef en lichtwisselproef zijn uitgevoerd; de rapportage scheidt behaalde waarden van doelen.
- Detectie voldoet ook met één kijker en tijdens tien minuten backenduitval aan de vastgestelde timinggrens. Een volle uploadwachtrij veroorzaakt getelde verliezen, geen vastloper of groeiend geheugenverbruik.
- Eventverlenging, maximale duur, pretriggerdekking, netwerkherstel, reboot en ontbrekende klok zijn getest.
- Backendtests gebruiken dezelfde contractfixtures voor exacte retries, 409, afsluiting vóór/na frames, nul frames, twee camera's en crashherstel van bestand plus database.
- Geen wifi-wachtwoorden, tokens of binaries met daarin credentials in Git. Geen afhankelijkheid van CP2102 na deployment.
- Elk onderdeel levert installatie-/buildinstructies, relevante tests en openstaande beperkingen. Alleen integratie mag de volledige keten als geslaagd markeren.

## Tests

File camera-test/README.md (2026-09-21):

# Eerste sketch: camera via wifi

Doel: beeld van de AI-Thinker ESP32-CAM met OV2640 beoordelen. Geen backend of bewegingsdetectie. MJPEG-livebeeld op 800 × 600 met PSRAM; zonder PSRAM 320 × 240. De witte flits-LED blijft uit.

## Gebruik na flashen

Voor bestaande wifi: kopieer `CameraTest/secrets.example.h` naar `CameraTest/secrets.h` en vul de netwerkgegevens in voordat je bouwt. `secrets.h` blijft buiten Git. De lokale configuratie gebruikt Skynet. Na verbinden staat het IP-adres in de seriële uitvoer; open dat adres of **http://wildcam-test.local/** vanaf hetzelfde netwerk. Werkt de naam niet, gebruik het IP-adres.

Zonder ingestelde netwerkgegevens, of wanneer verbinden binnen 20 seconden mislukt, start het onderstaande test-accesspoint. Bij ingestelde gegevens blijft de camera ook opnieuw proberen met het bestaande netwerk te verbinden.

1. Schakel de voeding uit, verwijder de GPIO0-GND-jumper en schakel weer in.
2. Verbind telefoon of laptop met **WildCam-Test**, wachtwoord **camera-test-32**.
3. Blijf verbonden wanneer je apparaat meldt dat dit netwerk geen internet heeft.
4. Open **http://192.168.4.1/**. Livebeeld start automatisch. Gebruik één kijker tegelijk.
5. Met **Stop** stop je de stream; **Open foto** opent een JPEG in hetzelfde tabblad. Ga terug om weer live te kijken.

Versie 2 gebruikt gewone HTML-formulieren voor Start en Stop, zonder JavaScript. De pagina bevat ook een link naar de directe MJPEG-stream op poort 81. Seriële logging meldt wanneer een kijker verbindt, het eerste frame is verstuurd en de verbinding sluit.

Deze test heeft een vast wifi-wachtwoord, instelbaar in `CameraTest/config.h`. Wie met dit netwerk verbonden is kan het beeld bekijken. Voor een toekomstige installatie het wachtwoord aanpassen.

## Build en flash

Vanuit deze map, met PlatformIO:

```powershell
pio run
pio run -t upload --upload-port COM5
pio device monitor --port COM5 --baud 115200
```

Vervang COM5 door de werkelijk gedetecteerde CP2102-poort. GPIO0 moet bij reset voor het uploaden aan GND liggen. Druk zo nodig op reset terwijl de uploader verbinding zoekt. Na upload GPIO0 losmaken en resetten.

Arduino IDE: open `CameraTest/CameraTest.ino`, gebruik het Espressif ESP32-boardpakket (de PlatformIO-build gebruikt Arduino ESP32 2.0.17), selecteer **AI Thinker ESP32-CAM**, uploadsnelheid 115200.

## Aansluiting CP2102

| CP2102 | ESP32-CAM |
| --- | --- |
| 5V / VBUS | 5V |
| GND | GND |
| TXD, 3,3V-logica | U0R / GPIO3 |
| RXD | U0T / GPIO1 |

Voed niet uit de 3,3V-pin. Bij onvoldoende USB-voeding: stabiele externe 5V-voeding (circa 1 A of meer), gedeelde GND, en CP2102-5V loslaten. Geen SD-kaart nodig.

## Controle op hardware

- Seriële monitor op 115200 toont PSRAM, camerastatus en het webadres.
- Controleer scherpte, kleur, oriëntatie en vloeiendheid gedurende enkele minuten.
- Test Stop, Start livebeeld, Open foto en opnieuw inschakelen.
- Bij camera-initfout: voeding uit en cameraflatkabel/pinout controleren.
- Bij brownout/herstarts: voeding en USB-kabel controleren.
- Geen COM-poort: controleer USB-datakabel en CP2102-driver in Apparaatbeheer.

Referentie voor camera-initialisatie en MJPEG: het officiële Espressif CameraWebServer-voorbeeld, https://github.com/espressif/arduino-esp32/tree/2.0.17/libraries/ESP32/examples/Camera/CameraWebServer .

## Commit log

2026-09-21 Add WildCam design documents and Wi-Fi camera test sketch
2026-09-21 Make camera controls work without JavaScript and support private Wi-Fi settings
2026-10-29 Herstructureer repository: WildCam, hardware en housing mappen
    - Design-documenten verplaatst naar WildCam/Design
    - Firmware-versies (Cline, Cline ino, Copilot) onder WildCam
    - Hardware-foto's naar hardware/, behuizing naar housing/
    - Bestanden die lokaal niet meer bestaan (README, BOUWINSTRUCTIE,
    camera-test, enkele stl/gcode) verwijderd
2026-10-29 Voeg camera-webserver testsketch toe
    ESP32-CAM als wifi-accesspoint met livebeeld en flits aan/uit.
2026-10-29 Voeg ESP32-CAM pinbeschrijving en foto achterkant toe
